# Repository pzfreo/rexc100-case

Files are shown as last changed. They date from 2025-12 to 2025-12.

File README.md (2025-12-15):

# Inverted PID Controller Enclosure (Inkbird DIN 1/16)

A robust, 3D-printable enclosure designed for a PID temperature control system. Designed for UK plugs. This design features an "inverted" shell architecture for easy printing and a passive "chimney effect" cooling system for the Solid State Relay (SSR).

## 📋 Features
* **Inverted Design:** The main shell prints upside down (roof on the build plate), requiring minimal supports.
* **Chimney Cooling:** Intake vents in the base and exhaust vents in the lid create a natural updraft through the SSR heatsink.
* **Friction Clamp Mounting:** A unique "Anvil & Hammer" system secures the Inkbird controller without needing difficult-to-remove stock brackets.
* **Reinforced Mounts:** "Dog-bone" reinforcement for the mains socket prevents boss snapping.
* **Configurable Fasteners:** Switch between self-tapping screws (prototyping) or heat-set inserts (production) in the code.

## 🛠️ Bill of Materials (BOM)

### Electronics
| Component | Spec / Search Term | Notes |
| :--- | :--- | :--- |
| **PID Controller** | Inkbird ITC-100 (1/16 DIN) | Standard 48x48mm front panel. |
| **SSR & Heatsink** | 25A SSR + DIN Rail Heatsink | Footprint approx 50x80mm. |
| **Power Inlet** | C14 Fused Switched Inlet | Standard 3-pin PC style inlet with rocker switch. 40mm mounting hole separation |
| **Mains Output** | UK 13A Socket (Panel Mount) | Standard 73mm square faceplate. |
| **Thermocouple** | K-Type Thermocouple + Terminal Block | 2-pole ceramic or plastic block. |

### Fasteners (Hardware)
* **Case Screws:** 4x M3 x 12mm Countersunk (for base plate).
* **Internal Mounts:** M3 Button Head or Cap Head screws (Lengths vary: 6mm - 10mm).
* **Clamp Screw:** 1x M3 x 15mm (approx) for the PID friction clamp.
* **Inserts (Optional):** M3 Brass Heat-Set Inserts (if running in Production Mode).

## 🖨️ Printing Guidelines

### Recommended Settings
* **Material:** **PETG or ABS/ASA**. (PLA is **not recommended** due to heat generated by the SSR).
* **Nozzle:** 0.4mm or 0.6mm.
* **Layer Height:** 0.2mm.
* **Infill:** 20-30% Grid or Gyroid.
* **Perimeters:** 3 walls minimum (for strength around screw bosses).

### Orientation
1.  **Shell (`pid_inv_shell.stl`):** Print **Upside Down** (Flat roof on the build plate).
    * *Supports:* Generally not required if your printer bridges well, but check the C14 cutout.
2.  **Base (`pid_inv_base.stl`):** Print flat on the build plate.

---

## 💻 Generating the Files (Python)

This project is defined parametrically using `build123d`. You can modify dimensions or toggle screw types by editing `case3b.py`.

### 1. Prerequisites
You need Python installed. Then install the CAD library and visualizer:

```bash
pip install build123d ocp-vscode
````

### 2\. Configuration (`case3b.py`)

Open the script and look for the configuration switch at the top:

```python
# False = Prototype Mode (Small pilot holes for M3 self-tapping screws)
# True  = Production Mode (Large holes for M3 heat-set inserts)
USE_INSERTS = False 
```

### 3\. Running the Script

To generate the STL files, simply run:

```bash
python case3b.py
```

  * This will create `pid_inv_shell.stl` and `pid_inv_base.stl` in the same directory.
  * It also generates STEP files that can be imported into CAD packages.
  * It will output the dimensions in the console.

### 4\. Visualizing the Design

To view the 3D model interactively (with "Ghost" components for fitment checking):

1.  Open `case3b.py` in VS Code.
2.  Run the script using the **OCP CAD Viewer** extension in VS Code.

-----

## 🔧 Assembly Guide

### 1\. The PID Friction Clamp

The PID controller is held in place by a clamp mechanism built into the case:

1.  Slide the Inkbird controller into the front cutout.
2.  Locate the threaded hole in the block **below** the controller (accessible from the open bottom).
3.  Insert a long M3 screw.
4.  As you tighten, the screw pushes the PID body **UP** against the solid brace (Anvil) near the roof, locking it in place.

### 2\. SSR Mounting

  * Apply a small amount of thermal paste between the SSR and the Heatsink if separate.
  * Mount the SSR assembly onto the two raised pillars on the Base Plate.
  * Ensure the grill slots are not blocked by wires.

### 3\. Wiring

  * **Thermocouple:** Route the stiff wire through the 3-pillar "Labyrinth" strain relief before connecting it to the terminal block.
  * **Cable Clearance:** Ensure the C14 power cables are bent sharply (90°) immediately after entering to avoid hitting the SSR.

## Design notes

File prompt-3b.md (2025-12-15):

# Master Design Prompt

**Project Goal:**
Create a two-part 3D printed enclosure for a PID temperature control system. The design is **"Inverted"**: the "Lid" acts as the main structural body (printed upside down), and the "Base" is a removable bottom plate.

**Core Components:**
1.  **PID Controller:** Inkbird ITC-100 (1/16 DIN Standard).
2.  **SSR:** Solid State Relay + Heatsink (50x80mm footprint).
3.  **Power:** UK Mains Socket (Standard 73mm square) + C14 Inlet (Fused/Switched).
4.  **Sensors:** K-Type Thermocouple Terminal Block.

---

### **Part A: The Base Plate (Bottom Cover)**
* **Thickness:** 5.0mm (Critical for thread engagement).
* **SSR Mounting:**
    * **Standoffs:** Do NOT use a solid block. Use two circular pillars (12mm dia) or rectangular bars to support the SSR corners only.
    * **Ventilation:** Cut a grill of 30mm slots directly between these standoffs (Bottom Intake).
* **Terminal Block:** Mount on a 5mm boss. Position this **40mm forward** from the rear edge to allow stiff thermocouple wires to bend naturally.
* **Fasteners:**
    * **Component Mounts:** Sized for M3 Self-Tapping Screws (2.8mm pilot holes) or Heat-Set Inserts (4.2mm) based on a boolean switch.
    * **Case Screws:** 4x M3 Countersunk Clearance holes in the corners.
    * **Gotcha Fix:** Ensure counterbores cut **UP** from the bottom face (Z=0), not down from the top.

### **Part B: The Shell (Inverted Body)**
* **Orientation:** Printed "Upside Down" (Roof on build plate at Z=0; Open bottom at Z=Height).
* **PID Mounting (The "Clamp & Anvil"):**
    * **The Anvil (Brace):** A solid block extending from the **Roof (Z=0)** down to the **Top of the PID**. This prevents the controller from floating up.
    * **The Hammer (Clamp):** A 10mm block located immediately **Below the PID** (near the open bottom).
    * **Access:** A vertical screw hole through the Hammer, accessible from the open bottom, pushing the PID **UP** against the Anvil.
* **UK Socket:**
    * **Right Boss:** Needs a "Dog Bone" reinforcement tail extending sideways to prevent snapping.
    * **Left Boss:** Bridge to the nearest wall for strength.
    * **Holes:** Sized for M3.5 (standard electrical screw) or M3 if prototyping.
* **C14 Inlet:**
    * **Location:** Rear wall, vertically centered.
    * **Reinforcement:** Add full-height "Pilasters" (12mm thick) next to the cutout to support the mounting screws.
    * **Clearance:** Ensure the screw cutter cylinders are long enough (30mm) to punch through these thick pilasters.
* **Ventilation (Chimney Effect):**
    * **Front Face:** SOLID (No vents).
    * **Top Face (Roof):** Grill slots directly above the SSR.
    * **Logic:** Cool air enters Base Grill → Rises through SSR → Exits Roof Grill.

### **Part C: "Gotcha" Avoidance Checklist**
1.  **Z-Axis Orientation:** Remember the shell is inverted. "Top" of the case is Z=0. "Bottom" opening is Z=Max.
2.  **Counterbore Direction:** Base plate holes must be cut from Z=0 upwards, leaving a solid shoulder for the screw head.
3.  **SSR Insulation:** Never place the SSR heatsink on a solid block of plastic; it insulates the heat. Use standoffs.
4.  **C14 Cable Clearance:** Leave at least **45mm of depth** behind the C14 inlet for the stiff power cables.
5.  **Thermocouple Wire Path:** K-Type wires are stiff springs. Do not place the terminal block too close to the strain relief pillars; they need ~20mm of "runway" to straighten out.

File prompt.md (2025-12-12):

**Role:** Act as a Senior Mechanical Design Engineer. Write a Python script using the `build123d` library to generate a parametric, 3D-printable industrial enclosure.

**1. Environment & Constraints**
* **Library:** `build123d` (Algebra mode preferred).
* **Visualizer:** `ocp_vscode` (Show Body, Lid, Cover, Washer, and transparent "Ghost" electronics).
* **Printer Constraint:** The final assembly length must fit on a **256x256mm build plate** (Target total length < 250mm).
* **Printability:** Design for FDM printing without supports (chamfers on overhangs, text on top faces).

**2. Global Case Settings**
* **Wall Thickness:** 2.0 mm.
* **Lid Thickness:** 4.0 mm.
* **Fillets:** 4.0 mm external corner radius.
* **Fasteners:** Design for M3 self-tapping screws.
* **Hole Type:** Use **Counterbores** (flat bottom) for all lids to ensure solid screw grip.

**3. Component Dimensions ("Ghost" Objects)**
* **REX-C100 PID:**
    * Bezel: 48x48mm, Depth 9mm.
    * Body: 44x44mm, Depth 80mm.
    * *Placement:* Front wall, centered.
* **SSR + Heatsink:**
    * Footprint: 50mm (W) x 80mm (L).
    * Height: 73mm.
    * *Placement:* Floor mounted, behind PID.
* **External Terminal Block:**
    * Size: 36mm (W) x 21mm (D) x 13mm (H).
    * *Placement:* External "Porch" on the rear wall.

**4. Design Requirements & Layout**

* **A. Internal Layout & Spacing:**
    * **Gap (PID to SSR):** 40mm (Wire routing).
    * **Gap (SSR to Rear Wall):** 45mm (Critical for bending stiff mains cable).
    * **Wiring Margin:** Add 40mm width margin for side cable routing.

* **B. Rear "Porch" (Left Side):**
    * Create a U-shaped extension on the **Left Side** of the rear wall.
    * **Walls:** Extend walls up from the porch floor (approx 18mm high).
    * **Wire Exit:** Rear-facing slot for external wires.
    * **Mounting:** Floor holes for the terminal block.

* **C. Cable Management (Right Side):**
    * Locate two (2) cable entry holes on the **Right Side** of the rear wall (spaced 22mm apart).
    * **Anchors:** Create two raised block anchors on the floor corresponding to the entries.
    * **Zip Tie Slots:** Large **5.0mm x 3.5mm** slots.
    * **Refinement:** Apply a **0.5mm fillet** to the slot edges to prevent cutting the zip ties.

* **D. Main Lid:**
    * Top-fitting lid, 4mm thick.
    * **Ventilation:** Grid of slots above the SSR area. Ribs must be **3mm thick** (6mm pitch).
    * **Label:** Emboss **"PID Temp" / "Controller"** (2 lines) on the top face (0.6mm height), oriented for reading from the front.
    * **Order of Operations:** Ensure ventilation is cut *before* text is embossed to avoid artifacts.

* **E. Terminal Safety Cover:**
    * A flat lid (4mm thick) that screws onto the Porch walls.
    * **Tolerance:** Ensure a **1.0mm air gap** between the cover and the main case wall.
    * **Safety Labels:** Engrave `+` and `-` symbols on the **Top Face** (0.6mm deep).
    * **Poka-yoke (Mistake Proofing):**
        1.  Offset the screw holes by 3mm (asymmetric) so the lid cannot be reversed.
        2.  Add a semi-circular "finger notch" on the rear edge to indicate orientation.

* **F. Accessories:**
    * Generate a separate **M3 Washer** (8mm OD, 2mm thick) for load distribution.

**5. Output Generation**
* Export four STLs: `pid_case_body.stl`, `pid_lid.stl`, `pid_term_cover.stl`, `pid_washer.stl`.
* Show an exploded assembly view in the visualizer.

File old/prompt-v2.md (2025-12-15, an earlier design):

This master prompt captures the exact specifications of the final V5.9 design, along with specific technical "guardrails" to prevent the bugs we encountered (floating parts, missing vents, `hull()` errors).

You can use this prompt to regenerate the project from scratch or to instruct another AI/developer on exactly how to build this specific version.

***

### Master Prompt: The "RexC100 Optimized" PID Controller Case

**Goal:**
Create a Python script using the `build123d` library to generate a high-quality, DFM-optimized enclosure for a RexC100 PID Controller, an SSR (Solid State Relay), and a UK Mains Socket. The design must be 3D-printable without support material ("support-free") and feature a "Chimney Effect" passive cooling system.

**Technical Constraints & Anti-Regression Rules:**
1.  **Absolute Coordinates Only:** Do not rely on relative face selection (`faces().sort_by(...)`) for critical positioning. Pre-calculate global `(x, y, z)` coordinates for the PID, SSR, and Socket centers at the start of the script and use `Locations((x,y,z))` for placement.
2.  **No `hull()` Operations:** Use simple boolean unions (`add(shape1 + shape2)`) to create reinforced shapes like the "Dog Bone" lid mounts. `hull()` is unstable in some library versions.
3.  **Solid Boolean Cuts:** For all vents (especially front/side walls), use **Solid Primitives** (`Box(..., mode=Mode.SUBTRACT)`) positioned to intersect the wall. Do not sketch 2D shapes on face surfaces, as this leads to "zero-thickness" errors where cuts fail to appear.
4.  **"Pilaster" Construction:** For the C14 inlet and side mounts, do not use floating cylinders. Build "Pilasters" (engaged columns) by unioning a `Cylinder` (boss) with a `Box` (support) that extends down to the floor (`Z=2.0`). This eliminates the need for 3D print supports.
5.  **Face Normal Safety:** When cutting the front vents, do not rely on plane normals. Use a cutter object that is thick enough to penetrate the wall in both directions (e.g., `Box(..., align=(Align.CENTER...))`).

**Design Specifications (V5.9 Standard):**

* **Global Dims:**
    * Wall Thickness: **2.0mm**
    * Lid Thickness: **4.0mm**
    * Fillet Radius: **4.0mm** (Vertical edges)
    * Base Chamfer: **1.0mm** (To prevent elephant's foot)

* **Layout Strategy (Split-Level):**
    * **PID:** Front-Left.
    * **SSR:** Front-Right. **Shifted +5mm Right** to clear the socket.
    * **UK Socket:** Top-Center-Left. **Shifted +15mm Back** and **+3mm Right** relative to PID. This creates a "DMZ" gap for wiring and reduces total case height.
    * **C14 Inlet:** Left Wall, aligned with SSR depth.
    * **Divider Wall:** **REMOVED** to improve airflow and wiring ease.

* **Thermal Management (Chimney Effect):**
    * **Intake:** Vertical slots on the **Front Face**, aligned with the SSR heatsink.
    * **Exhaust:** Matching slots on the **Lid**, directly above the SSR.
    * **Floor:** Grid of slots directly under the SSR.

* **Fasteners & Mounts:**
    * **C14 Mounts:** M3 inserts (Hole 4.2mm), Boss Depth **8.0mm**. Built as Pilasters.
    * **Socket Mounts:** M3.5 inserts (Hole 4.8mm), Boss Depth **6.0mm**. Built as "Dog Bones" (Circle + Rectangle union) connecting to the lid side walls.
    * **Lid Screws:** M3 Counterbored holes in corners.

**Output:**
The script must generate and export four STL files:
1.  `pid_case_body.stl`
2.  `pid_lid.stl`
3.  `pid_term_cover.stl` (Rear safety cover)
4.  `pid_washer.stl` (Safety washer)

**Visualization:**
Include `show_object()` calls with transparency for the "Ghost" components (PID body, SSR, Mains Block) to verify fitment visually.

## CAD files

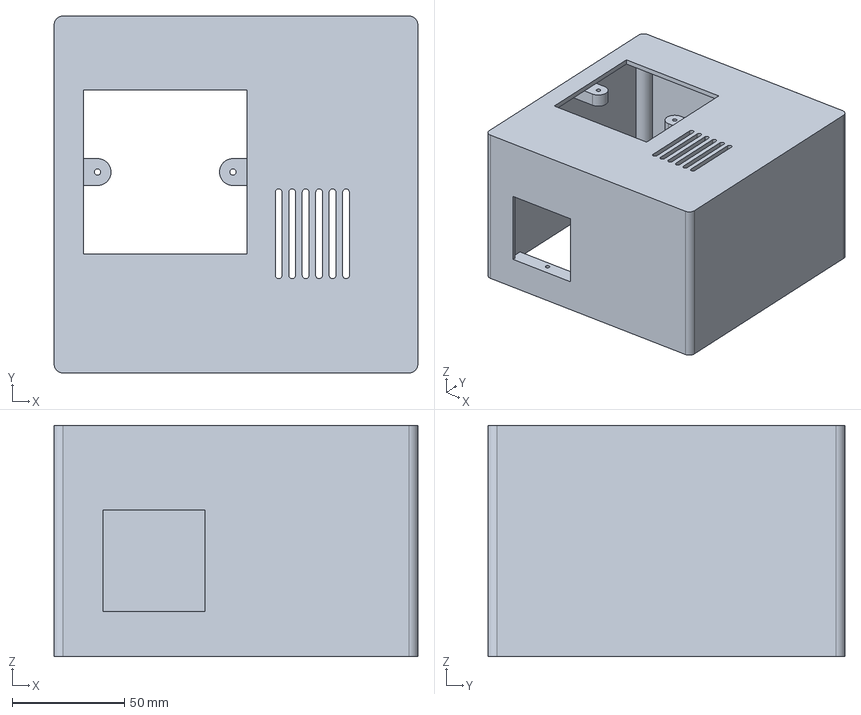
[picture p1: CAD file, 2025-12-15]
pid_inv_shell.step
162.0 x 159.0 x 103.0 mm

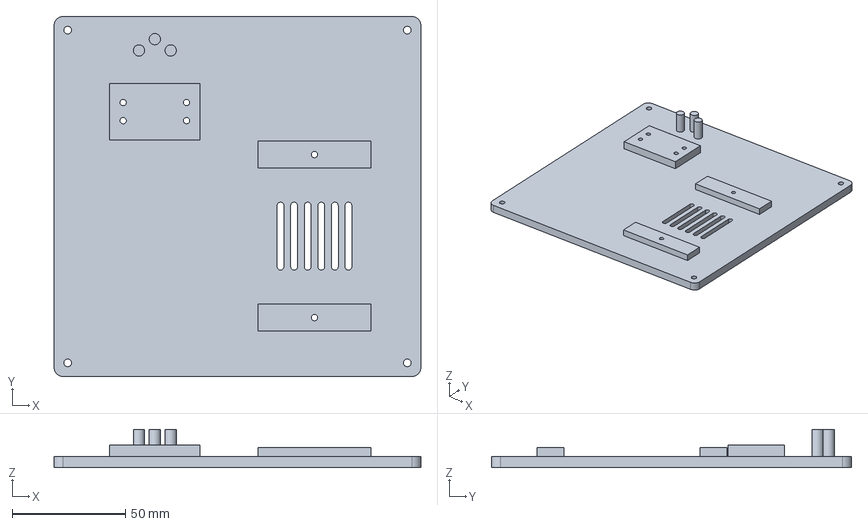
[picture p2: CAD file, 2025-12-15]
pid_inv_base.step
162.0 x 159.0 x 17.0 mm

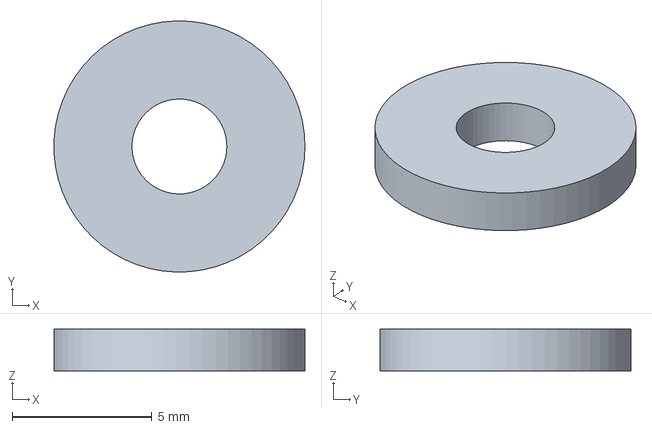
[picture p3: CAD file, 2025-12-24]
pid_m3_washer.step
8.99 x 9.00 x 1.50 mm

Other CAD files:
pid_inv_base.stl
pid_inv_shell.stl
pid_m3_washer.stl

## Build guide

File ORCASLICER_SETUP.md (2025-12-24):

# OrcaSlicer Profile Setup for PID Case

## Quick Import Instructions

### 1. Import Filament Profile

1. Open OrcaSlicer
2. Go to **Filament** tab (top of window)
3. Click the **hamburger menu** (☰) next to filament dropdown
4. Select **Import** → **Import configs...**
5. Navigate to: `OrcaSlicer_ABS_Filament_Profile.json`
6. Click **Open**
7. Profile appears as: **"ABS - PID Case Optimized"**

### 2. Import Print Profile

1. Go to **Process** tab (top of window)
2. Click the **hamburger menu** (☰) next to process dropdown
3. Select **Import** → **Import configs...**
4. Navigate to: `OrcaSlicer_PID_Case_Print_Profile.json`
5. Click **Open**
6. Profile appears as: **"PID Case - ABS Structural"**

### 3. Quick Setup

1. **Printer**: Select "Bambu Lab P1S 0.4 nozzle"
2. **Filament**: Select "ABS - PID Case Optimized"
3. **Process**: Select "PID Case - ABS Structural"
4. **Plate Type**: Textured PEI Plate (or Cool Plate with ABS slurry)

---

## Profile Settings Breakdown

### Filament Profile: "ABS - PID Case Optimized"

**Temperatures:**
- Nozzle: 250°C (all layers)
- Bed: 100°C (all layers)
- Chamber: 45°C (P1S automatic)

**Cooling Strategy:**
- First 5 layers: 0% fan (prevent warping)
- Later layers: 0-15% fan maximum (prevent delamination)
- Bridges/overhangs: 15% fan

**Why these settings:**
- Low cooling prevents ABS warping on large 160mm+ parts
- Higher temps improve layer adhesion
- Chamber temp keeps ambient warm for consistent printing

**Retraction:**
- Distance: 0.8mm (direct drive)
- Speed: 40mm/s
- Z-hop: 0.2mm (prevents scraping on travel)

---

### Print Profile: "PID Case - ABS Structural"

**Layer Settings:**
- Layer height: 0.2mm (good detail for chamfers)
- First layer: 0.2mm (same height for consistency)
- Line width: 0.42mm (slightly wider for strength)

**Walls & Strength:**
- Perimeters: **4 walls**
  - Your case has 3mm thick walls
  - 4 perimeters @ 0.42mm = 1.68mm of solid wall
  - Rest filled with 30% infill
- Top layers: 6 (solid roof)
- Bottom layers: 6 (solid base)

**Infill:**
- Pattern: Gyroid (strong + efficient)
- Density: 30% (good strength/weight balance)
- Top surface: Monotonic (smooth professional finish)

**Speeds:**
- First layer: **25mm/s** (critical for adhesion)
- Outer walls: 45mm/s (quality)
- Inner walls: 150mm/s (faster)
- Infill: 150mm/s (faster)
- Bridges: 25mm/s (socket boss bridges)
- Travel: 200mm/s

**Adhesion:**
- Brim: **10mm width** (MANDATORY for large ABS parts)
- Prevents corner lifting on 164×161mm base
- Elephant foot compensation: 0.15mm

**Hole Compensation:**
- XY hole compensation: **0.05mm**
- Makes heat set insert holes slightly tighter
- Ensures chamfers are proper size
- Helps with precise 0.3mm tolerance fits

**Accelerations:**
- First layer: 500mm/s² (gentle for adhesion)
- Outer walls: 3000mm/s² (quality)
- Default: 5000mm/s² (speed)

---

## Print Recommendations

### Base Plate

**Orientation:** Print as-is (feet indents facing down)
- Bottom surface against bed
- No supports needed
- Brim automatically generated

**Expected Results:**
- SSR mounting chamfers: Clean (top surface)
- Terminal block chamfers: Clean (top surface)
- Feet indents: Perfect (against bed)
- Print time: ~10-12 hours

### Shell

**Orientation:** Print **UPSIDE DOWN** (roof on bed)
- Roof surface against bed
- Corner posts print perfectly vertical
- Socket bosses extend upward (no supports needed)
- Chamfers accessible from below

**Why upside down:**
✅ Corner post chamfers face up (clean print)
✅ Socket boss chamfers face up (accessible)
✅ Roof surface perfect (against bed)
✅ No supports needed
✅ Better overall quality

**Expected Results:**
- Corner post chamfers: Perfect
- Socket boss chamfers: Perfect
- C14 chamfers: Clean (horizontal, will print fine)
- PID clamp chamfer: Clean
- Print time: ~14-18 hours

---

## Critical Pre-Print Checklist

### Before Starting Print:

- [ ] **Enclosure closed** (chamber needs to reach 45°C)
- [ ] **Bed cleaned** with IPA
- [ ] **ABS slurry applied** (or bed properly prepared)
- [ ] **Filament dry** (ABS absorbs moisture)
- [ ] **Brim enabled** in profile (should auto-enable)
- [ ] **Part cooling fan verified** (should be 0% first layers)
- [ ] **Print orientation correct:**
  - Base: Normal (feet down)
  - Shell: Upside down (roof down)

### During Print:

- [ ] First layer adhering well (watch first 5 minutes)
- [ ] No corner lifting
- [ ] No drafts hitting printer
- [ ] Chamber temp stable

### After Print Completes:

- [ ] **DO NOT open enclosure immediately**
- [ ] Let chamber cool naturally to <60°C (~30-45 min)
- [ ] Then remove print
- [ ] Remove brim carefully with flush cutters

---

## Heat Set Insert Installation

**After printing, before installing inserts:**

1. **Let parts rest 24 hours** (ABS continues to harden)
2. **Clean chamfer entrances** with deburring tool if needed

**Settings for heat set inserts:**
- Soldering iron temp: **280-300°C**
- Insert type: M3 (4.0mm OD × 5.7mm L) or M3.5 (4.6mm OD × 6.0mm L)
- Dwell time: 4-6 seconds
- Pressure: Medium (let weight of iron do work)

**Chamfer benefits:**
- 0.8mm deep chamfers guide inserts straight
- 5.5mm/5.8mm diameter prevents mushrooming
- Easy to see alignment before insertion

**Insert locations (with chamfers):**
- ✅ SSR bosses: 2× M3 (top of base)
- ✅ Terminal bosses: 4× M3 (top of base) - **if enabled**
- ✅ Corner posts: 4× M3 (bottom of shell)
- ✅ Socket bosses: 2× M3.5 (bottom/inside of shell)
- ✅ C14 pilasters: 2× M3 (outside of shell)
- ✅ PID clamp: 1× M3 (bottom/inside of shell)

---

## Troubleshooting

### Warping/Corners Lifting

**Solution:**
1. Increase brim to 15mm
2. Add draft shield:
   - Process → Support → Draft shield: **Enabled**
3. Reduce bed temp to 95°C
4. Ensure enclosure fully closed
5. Add "mouse ears" to corners in slicer

### Layer Delamination

**Solution:**
1. Reduce part cooling to 0% completely
2. Increase chamber temp (check P1S chamber is enclosed)
3. Increase nozzle temp to 255°C
4. Check for drafts

### Stringing

**Solution:**
1. Enable Z-hop: 0.2mm (already in profile)
2. Increase retraction to 1.0mm
3. Reduce nozzle temp to 245°C
4. Enable "Avoid crossing perimeters"

### First Layer Not Sticking

**Solution:**
1. Clean bed thoroughly with IPA
2. Apply ABS slurry (ABS dissolved in acetone)
3. Increase first layer bed temp to 105°C
4. Slow first layer to 20mm/s
5. Increase brim to 15mm

### Chamfers Not Clean

**Solution:**
- Likely printing orientation issue
- Verify shell is upside down
- Increase outer wall speed to 60mm/s
- Enable "Detect overhang wall" (already enabled)

---

## Material Estimates

**Base Plate:**
- Material: ~180-220g
- Cost: ~$5-7 (at $25/kg)
- Time: 10-12 hours

**Shell:**
- Material: ~250-300g
- Cost: ~$7-10 (at $25/kg)
- Time: 14-18 hours

**Total Project:**
- Material: ~430-520g ABS
- Cost: ~$12-15
- Time: 24-30 hours
- Inserts needed: 11-15 pieces (depending on configuration)

---

## Post-Processing (Optional)

### Acetone Vapor Smoothing

**For glossy professional finish:**

1. **After assembly** (don't smooth before inserts!)
2. Place part in sealed container
3. Add acetone-soaked paper towel (don't let acetone touch part)
4. Close container, wait 5-30 minutes
5. Remove part, let cure 24h

**Warning:** Can affect dimensional accuracy - don't use if tolerances critical.

---

## Profile Modifications

### If Printing Different Material:

**PETG Adjustments:**
- Nozzle: 235-245°C
- Bed: 75-85°C
- Chamber: Not needed (can print with door open)
- Cooling: 30-50% after layer 3
- Warping: Much less issue, brim optional

**PLA+CF Adjustments:**
- Nozzle: 220-230°C (hardened steel required!)
- Bed: 60°C
- Chamber: Not needed
- Cooling: 100% after layer 3
- Infill: Reduce to 20% (CF adds strength)

### If Changing Size/Scale:

**Smaller parts (<100mm):**
- Reduce brim to 5mm
- Can increase speeds by 20%

**Larger parts (>200mm):**
- Increase brim to 15-20mm
- Add draft shield mandatory
- Slow first layer to 20mm/s
- Consider splitting model

---

## Questions?

These profiles are specifically optimized for:
- ✅ Bambu P1S with 0.4mm nozzle
- ✅ ABS filament
- ✅ Large structural parts (160mm+)
- ✅ Heat set insert compatibility
- ✅ Your specific case design (3mm walls, chamfers, etc.)

Tested with: eSUN ABS+, Polymaker PolyLite ABS

**Note:** First print is always a learning experience. Watch the first layer carefully and be ready to adjust bed adhesion if needed!

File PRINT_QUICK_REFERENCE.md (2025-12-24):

# PID Case - Quick Print Reference Card

Print this page and keep next to printer!

---

## Profile Selection

```
┌─────────────────────────────────────────┐
│ Printer:  Bambu Lab P1S 0.4 nozzle      │
│ Filament: ABS - PID Case Optimized      │
│ Process:  PID Case - ABS Structural     │
│ Plate:    Textured PEI + ABS slurry     │
└─────────────────────────────────────────┘
```

---

## Part Orientations

### Base Plate
```
  ┌─────────────────┐
  │                 │  ← Top (holes/bosses face up)
  │    BASE         │
  │                 │
  └─────────────────┘
 ═══════════════════  ← Bed (feet indents down)
```
**Print as-is. No rotation needed.**

### Shell
```
 ═══════════════════  ← Bed (roof surface down)
  ┌─────────────────┐
  │                 │
  │    SHELL        │
  │                 │  ← Top (open bottom faces up)
  └─────────────────┘
```
**FLIP UPSIDE DOWN. Roof on bed!**

---

## Critical Settings Checklist

**Before Slicing:**
- [ ] Shell oriented upside down
- [ ] Brim: 10mm (auto-enabled in profile)
- [ ] Supports: OFF (not needed)

**Before Printing:**
- [ ] Enclosure CLOSED
- [ ] Bed cleaned with IPA
- [ ] ABS slurry applied
- [ ] Filament loaded and dry
- [ ] No drafts

**During Print:**
- [ ] Watch first 5 minutes
- [ ] Verify brim adhering
- [ ] Chamber at 45°C

**After Completion:**
- [ ] WAIT 30-45 min before opening
- [ ] Let chamber cool to <60°C
- [ ] Then remove part

---

## Temperatures

```
╔══════════════════════════════╗
║  Nozzle:  250°C              ║
║  Bed:     100°C              ║
║  Chamber: 45°C (automatic)   ║
╚══════════════════════════════╝
```

---

## Print Times & Material

| Part  | Time | Material | Cost  |
|---|---|---|---|
| Base  | 10-12h  | 180-220g | $5-7  |
| Shell | 14-18h  | 250-300g | $7-10 |
| TOTAL | 24-30h  | 430-520g | $12-15|

---

## Heat Set Insert Guide

**Iron Temperature:** 280-300°C
**Dwell Time:** 4-6 seconds
**Pressure:** Medium (let iron weight do work)

### Insert Count (Your Config)
```
SSR:       2× M3    ✓ Inserts
Terminal:  4× M3    ✗ Screws
Corners:   4× M3    ✓ Inserts
Socket:    2× M3.5  ✓ Inserts
C14:       2× M3    ✓ Inserts
PID Clamp: 1× M3    ✓ Inserts

Total inserts needed: 11 pieces
```

**Buy:**
- M3 inserts: 9 pieces (4.0mm OD × 5.7mm L)
- M3.5 inserts: 2 pieces (4.6mm OD × 6.0mm L)

---

## Common Issues - Quick Fixes

| Problem | Quick Fix |
|---|---|
| **Corners lifting** | Increase brim to 15mm, verify enclosure closed |
| **First layer not sticking** | Clean bed, apply ABS slurry, increase bed to 105°C |
| **Warping mid-print** | Check for drafts, ensure chamber 45°C |
| **Stringing** | Already optimized, try reducing temp to 245°C |
| **Layer gaps** | Reduce cooling to 0%, increase temp to 255°C |

---

## Bambu P1S AMS Settings

**If using AMS:**
- Slot 1: ABS (this profile)
- Drying: 65°C for 6+ hours before print
- Humidity: Keep <15% if possible

**Multi-color not recommended** for structural parts.

---

## Safety Reminders

⚠️ **ABS emits styrene fumes**
- Print in ventilated area
- Use air filter if available
- Don't print in living spaces

🔥 **Fire safety**
- Don't leave unattended for long prints
- Ensure smoke detector nearby

---

## Post-Print Workflow

1. ⏱️  **Wait 30-45 min** (enclosure closed)
2. 🌡️  **Chamber <60°C** before opening
3. 🔧  **Remove carefully** (may still be warm)
4. ✂️  **Remove brim** with flush cutters
5. 🕐  **Rest 24h** before installing inserts
6. 🔥  **Install inserts** at 280-300°C
7. 🔩  **Assemble** case

---

## Profile Files Location

```
/Users/paul/repos/pid-case/
├── OrcaSlicer_ABS_Filament_Profile.json
├── OrcaSlicer_PID_Case_Print_Profile.json
└── ORCASLICER_SETUP.md (detailed instructions)
```

---

**Version:** 1.0
**Optimized for:** Bambu P1S + ABS + Large structural parts
**Last updated:** 2024

---

**Emergency Stop Conditions:**
- Visible smoke/burning smell → STOP
- Nozzle clogging repeatedly → STOP
- Part completely detached → STOP
- Layers visibly separating → STOP

**Good luck with your print! 🎯**

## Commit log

2025-12-12 side by side
    [pid_case_body.stl, pid_lid.stl, pid_term_cover.stl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]
2025-12-15 added action
    [pid_inv_base.step, pid_inv_base.stl, pid_inv_shell.step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]
